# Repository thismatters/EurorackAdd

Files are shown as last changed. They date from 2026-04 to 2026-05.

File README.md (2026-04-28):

# Simple Add

This simple adder could come from any textbook which introduces op-amp circuits. Really simple, pretty useful too!

The KiCAD project here uses the library/footprints [found in my companion repo](https://github.com/thismatters/EurorackKiCAD).

## Width

7hp on an [Intellijel 1U rack](https://intellijel.com/support/1u-technical-specifications/).

## Inputs

Three signal jacks

## Outputs

One signal jack with the sum of the three inputs

## Vendors

There are part numbers in the [BOM](add.csv) for many of the parts (not for basic passives though) at the following vendors:

* [Mouser](https://www.mouser.com): Needs no introduction. Get your ICs from here (or [digikey](https://www.digikey.com)).
* [Tayda Electronics](https://www.taydaelectronics.com/): Good supplier for passive components; audio jacks, and potentiometers. Their audio jacks are slightly smaller than the thonkiconn from thonk.
* [Love My Switches](https://lovemyswitches.com/): Has [really good knobs](https://lovemyswitches.com/anodized-aluminum-knob-the-lo-fi-1-4-smooth-shaft-12-5mm-od/) to go on those potentiometers!
* [OSHPark](https://oshpark.com/): Fast and (relatively) cheap PCB manufacturer. Prototype run pending.

## Changelog

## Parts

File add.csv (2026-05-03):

Reference | Qty | Value | Footprint | Vendor | PartNum
C1,C2 | 2 | 22u 50V | Capacitor_THT:CP_Radial_D5.0mm_P2.50mm
C3 | 1 | 100n | Capacitor_SMD:C_0805_2012Metric
D1,D2 | 2 | BAT54S | Package_TO_SOT_SMD:SOT-23 | Mouser | 863-BAT54SLT1G
J1 | 1 | Conn_02x05_Odd_Even | Eurorack:PinHeader_2x05_P2.54mm_Vertical | Tayda | A-2939
J2 | 1 | in0 | Eurorack:AudioJack2_Tayda_A-2566 | Tayda | A-2566
J3 | 1 | in1 | Eurorack:AudioJack2_Tayda_A-2566 | Tayda | A-2566
J4 | 1 | in2 | Eurorack:AudioJack2_Tayda_A-2566 | Tayda | A-2566
J5 | 1 | out | Eurorack:AudioJack2_Tayda_A-2566 | Tayda | A-2566
J6,J8 | 2 | Conn_01x03_Pin | Connector_PinHeader_2.54mm:PinHeader_1x03_P2.54mm_Vertical
J7,J9 | 2 | Conn_01x03_Socket | Connector_PinSocket_2.54mm:PinSocket_1x03_P2.54mm_Vertical
M1,M2 | 2 | Standoff | Eurorack:Standoff_M2.5x0.45-11mm | Digikey | 732-10549-ND
M3,M4,M5,M6 | 4 | Screw | Eurorack:Screw_M2.5x0.45-6mm | Digikey | 36-29301-ND
R1,R2 | 2 | 10 | Resistor_SMD:R_0805_2012Metric
R3,R4,R5,R6,R7,R8 | 6 | 100K | Resistor_SMD:R_0805_2012Metric
R9 | 1 | 1K | Resistor_SMD:R_0805_2012Metric
U1 | 1 | TL072 | Package_SO:SOIC-8_3.9x4.9mm_P1.27mm | Mouser | 595-TL072CDR

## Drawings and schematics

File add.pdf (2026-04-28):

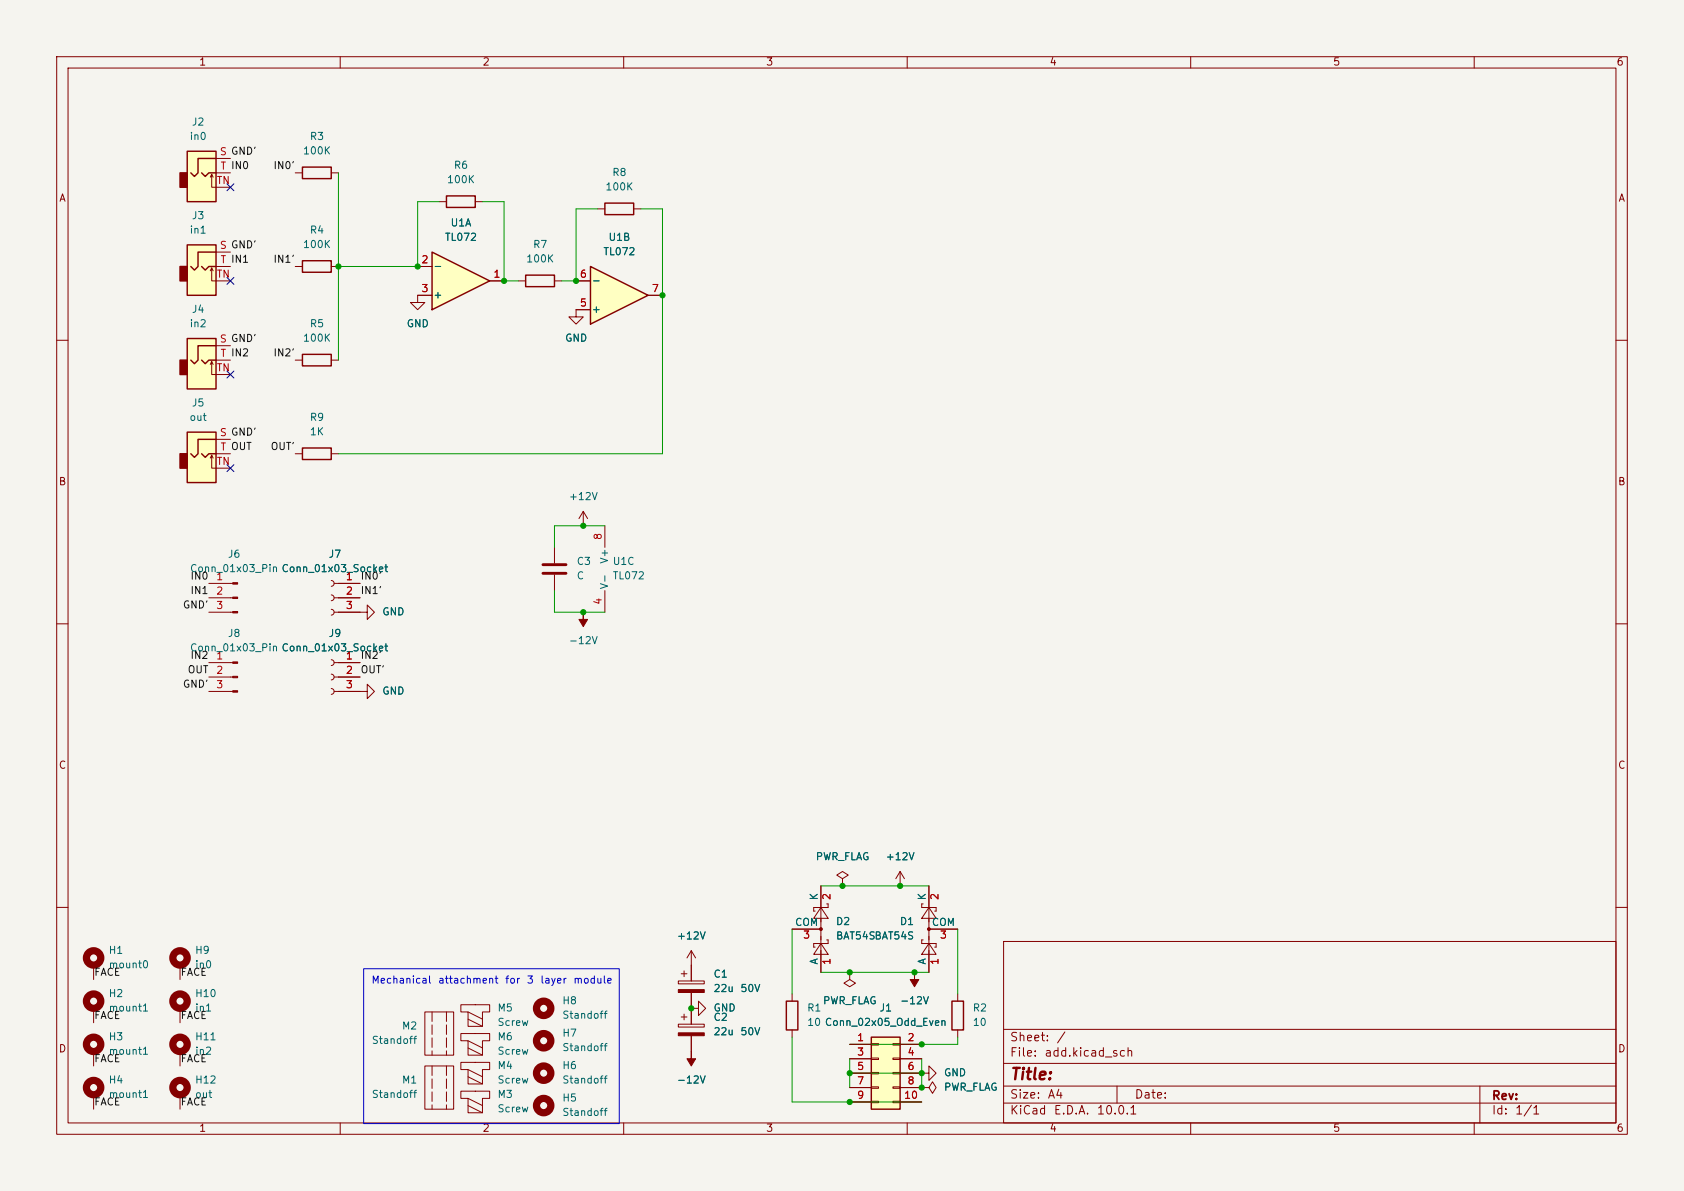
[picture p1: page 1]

Screw M5

5 5 | 6 6
7 7 | 8 8

KiCad E.D.A. 10.0.1 | Id: 1/1

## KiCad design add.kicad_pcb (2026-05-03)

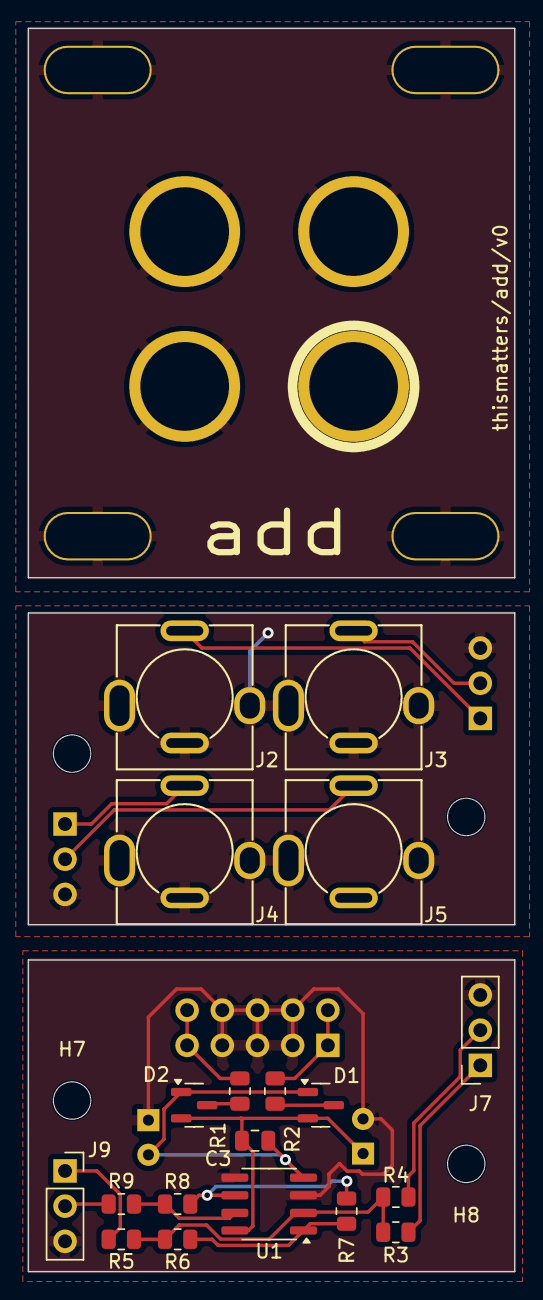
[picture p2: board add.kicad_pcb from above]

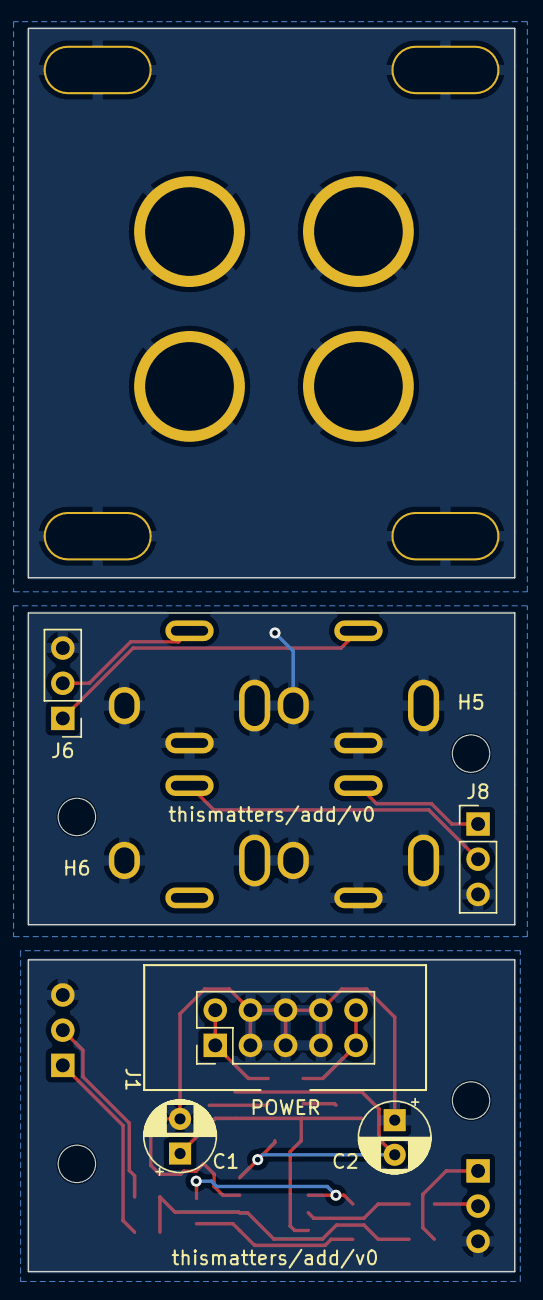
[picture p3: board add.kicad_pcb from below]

Board: 2 copper layers, 35.1 x 89.7 mm, 36 parts (7 on the bottom side), 21 nets.

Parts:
C1, C2: 22u 50V; CP_Radial_D5.0mm_P2.50mm
C3: 100n; C_0805_2012Metric
D1, D2: BAT54S; SOT-23
H1: mount0; Mech-MountingHole
H2, H3, H4: mount1; Mech-MountingHole
H5, H6, H7, H8: Standoff; MountingHole_2.7mm_M2.5
H9: in0; Mech-AudioJack-Hole-Input
H10: in1; Mech-AudioJack-Hole-Input
H11: in2; Mech-AudioJack-Hole-Input
H12: out; Mech-AudioJack-Hole-Output
J1: Conn_02x05_Odd_Even; PinHeader_2x05_P2.54mm_Vertical
J2: in0; AudioJack2_Tayda_A-2566
J3: in1; AudioJack2_Tayda_A-2566
J4: in2; AudioJack2_Tayda_A-2566
J5: out; AudioJack2_Tayda_A-2566
J6, J8: Conn_01x03_Pin; PinHeader_1x03_P2.54mm_Vertical
J7, J9: Conn_01x03_Socket; PinSocket_1x03_P2.54mm_Vertical
R1, R2: 10; R_0805_2012Metric
R3, R4, R5, R6, R7, R8: 100K; R_0805_2012Metric
R9: 1K; R_0805_2012Metric
U1: TL072; SOIC-8_3.9x4.9mm_P1.27mm

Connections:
+12V: C1.1, C3.1, D1.2 (K), D2.2 (K), U1.8 (V+)
-12V: C2.2, C3.2, D1.1 (A), D2.1 (A), U1.4 (V-)
/FACE: H1.1 (1_1), H2.1 (1_1), H3.1 (1_1), H4.1 (1_1), H9.1 (1_1), H10.1 (1_1), H11.1 (1_1), H12.1 (1_1)
/GND': J2.S, J2.TN, J3.S, J3.TN, J4.S, J4.TN, J5.S, J6.3, J8.3
/IN0: J2.T, J6.1
/IN0': J7.1, R3.1
/IN1: J3.T, J6.2
/IN1': J7.2, R4.1
/IN2: J4.T, J8.1
/IN2': J9.1, R5.1
/OUT: J5.T, J8.2
/OUT': J9.2, R9.1
GND: C1.2, C2.1, J1.3, J1.4, J1.5, J1.6, J1.7, J1.8, J7.3, J9.3, U1.3 (+), U1.5 (+)
unnamed: D1.3 (COM), R2.1
unnamed: D2.3 (COM), R1.1
unnamed: J1.1, J1.2, R2.2
unnamed: J1.9, J1.10, R1.2
unnamed: R6.2, R7.1, U1.1
unnamed: R8.2, R9.2, U1.7
unnamed: R3.2, R4.2, R5.2, R6.1, U1.2 (-)
unnamed: R7.2, R8.1, U1.6 (-)

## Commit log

2026-05-03 add bom
    [add.csv]
2026-05-03 update bom for sync
    [add.csv, add.kicad_pcb, add.kicad_sch]
2026-05-03 fix capacitor value
    [add.csv, add.kicad_pcb, add.kicad_sch]
2026-05-03 normal inputs to ground
    [add.kicad_pcb, add.kicad_sch]
